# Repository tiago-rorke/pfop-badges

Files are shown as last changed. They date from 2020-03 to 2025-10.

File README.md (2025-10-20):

# Badges from Other Planets

I made these supercapacitor powered badges for [Nowhere 2019](https://www.goingnowhere.org/), a regional burn near Zaragoza, Spain, for our fledgling barrio "People from Other Planets".

I wanted to try to use supercapacitors to avoid consuming hundreds of non-rechargeable coin cell batteries whilst keeping the design as simple as possible. Because 5V supercaps are considerably more expensive, I've used a pair of 2.5V caps in series, with a 2.5V zener across each cap to prevent overcharging.  Not sure of the safety of this, the small amount of the use these boards have seen so far haven't yet led to any explosions, but none-the-less **use these at your own risk!**

I settled on a pair of 4.7F caps in series as a balance between cost/size/capacity, which for these two example sketches seem to provide around an hour of interaction and blinking lights after about 1 min of charging.  Without PWM the LEDs I chose are blindingly bright, I would suggest using larger resistors or different LEDs.

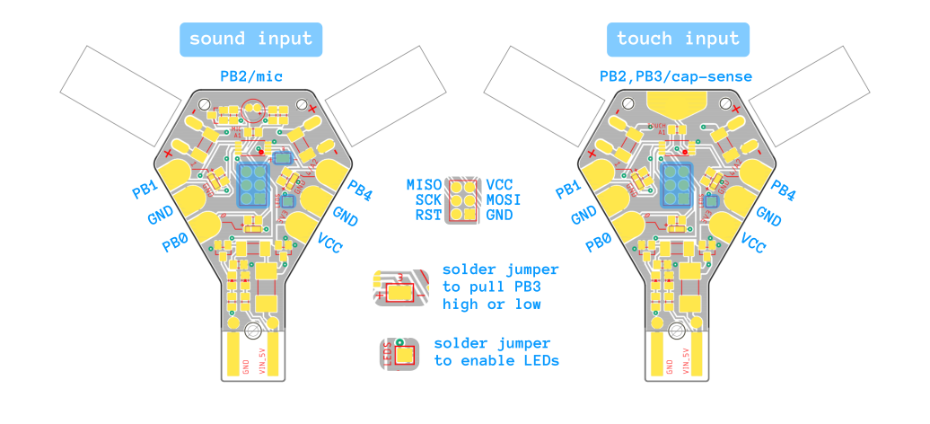
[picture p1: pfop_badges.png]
PFOP badges pinouts


There are two versions of the board, one with an eletret microphone and amplifier for reacting to sound, the other with a 2.2M resistor for doing capacitive touch sensing.

The charging circuit uses a mosfet and zener to switch on a green LED once the capacitors are fully charged.  I originally used a 5.1V zener which worked in the prototype circuit, but this didn't work with the zeners I put on the finished boards, maybe the 5.1V is a bit too high for usb voltages. I later experimented with some different values and eventually settled on a 3.9V zener that seemed to work well. Not sure why the zener voltage had to be so low, but the green LED would only start to turn on as the circuit approached the USB voltage.  The usb VBUS contact is split in two, to simultaneously connect a red led when the board is plugged in to charge, a hack which seems to work most of the time.  The capacitor inrush current is limited by a 1W resistor, which can get a bit toasty and should probably be bigger.

I made some adafruit inspired led-sequins, along with some sewable transistor break-outs, which are included in the board layouts.

The silkscreen designs on the back of the boards are by fellow bairro member [Luke Andrews](http://lukeandrewsdesign.com/), and the PFOP logo is by the barrio lead [Rob Allison](http://www.robertallison.co.uk/).

We also disassembled a bunch of old laptop batteries, removed any good cells and put them into [empty powerbanks](https://www.aliexpress.com/item/32966395604.html) to provide charging units for the badges, and to use as power sources for other activities we did at the burn in our desert makerspace :).

## BOM

| | | qty |
|---|---|---|
| capacitors 4.7F | [farnell](https://pt.farnell.com/samxon/dre475s0eg20rrdap/cap-4-7f-2-5v-double-layer-radial/dp/2800103) | 2 |
| attiny45 | [mouser](https://pt.mouser.com/ProductDetail/Microchip-Technology-Atmel/ATTINY45-20XU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) | 1 |
| white leds | [TME](https://www.tme.eu/pt/en/details/ll-r3014w-w5m-q10/smd-white-leds/lucky-light/) | 3 |
| red led | [TME](https://www.tme.eu/pt/en/details/ll-s172sc-2s/smd-colour-leds/lucky-light/) | 1 |
| green led | [TME](https://www.tme.eu/pt/en/details/el17-215sygc_53/smd-colour-leds/everlight/) | 1 |
| 3.3v regulator | [TME](https://www.tme.eu/pt/en/details/ap7313-33srg-7/ldo-unregulated-voltage-regulators/diodes-incorporated/) | 1 |
| 2.7v zener | [TME](https://www.tme.eu/pt/en/details/tzmb2v7-gs08/smd-zener-diodes/vishay/) | 2 |
| 3.9v zener | [TME](https://www.tme.eu/pt/en/details/bzv55c3v9-lge/smd-zener-diodes/luguang-electronic/bzv55c3v9/) | 1 |
| 2n7000 mosfet | [TME](https://www.tme.eu/pt/en/details/2n7002lt1g/smd-n-channel-transistors/on-semiconductor/) | 1 |
| resistor power 5.6R 1W | [TME](https://www.tme.eu/pt/en/details/smd2512-5r6/2512-smd-resistors/royal-ohm/25121wj056jt4e/) | 1 |
| resistor led 100R | [TME](https://www.tme.eu/pt/en/details/rc0805fr-07100r/0805-smd-resistors/yageo/rc0805fr-07100rl/) | 5 |
| resistor 10k | [TME](https://www.tme.eu/pt/en/details/smd0805-10k-1%25/0805-smd-resistors/royal-ohm/0805s8f1002t5e/) | 1 |
| *touch version* | | |
| resistor 2.2M | [TME](https://www.tme.eu/pt/en/details/smd0805-2m2/0805-smd-resistors/royal-ohm/0805s8j0225t5e/) | 1 |
| *sound version* | | |
| electret microphone | [aliexpress](https://www.aliexpress.com/item/10pcs-bag-4-5-2-2mm-condenser-electret-microphone-pickup-52DB/32262612470.html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,searchweb201602_7_10065_10068_319_10059_10884_317_10887_10696_321_322_10084_453_10083_454_10103_10618_10304_10307_10820_10301_10821_537_536,searchweb201603_52,ppcSwitch_0&algo_expid=e5ac956f-4788-4c7e-8c49-3e065ae08252-0&algo_pvid=e5ac956f-4788-4c7e-8c49-3e065ae08252) | 1 |
| bc847 transistor | [TME](https://www.tme.eu/pt/en/details/bc847be6327/npn-smd-transistors/infineon-technologies/) | 1 |
| resistor 10k | [TME](https://www.tme.eu/pt/en/details/smd0805-10k-1%25/0805-smd-resistors/royal-ohm/0805s8f1002t5e/) | 1 |
| resistor 100k | [TME](https://www.tme.eu/pt/en/details/crcw0805100kfktabc/0805-smd-resistors/vishay/) | 1 |
| cap 0.1uF | [TME](https://www.tme.eu/pt/en/details/cc0805krx7r9104/0805-mlcc-smd-capacitors/yageo/cc0805krx7r9bb104/) | 1 |

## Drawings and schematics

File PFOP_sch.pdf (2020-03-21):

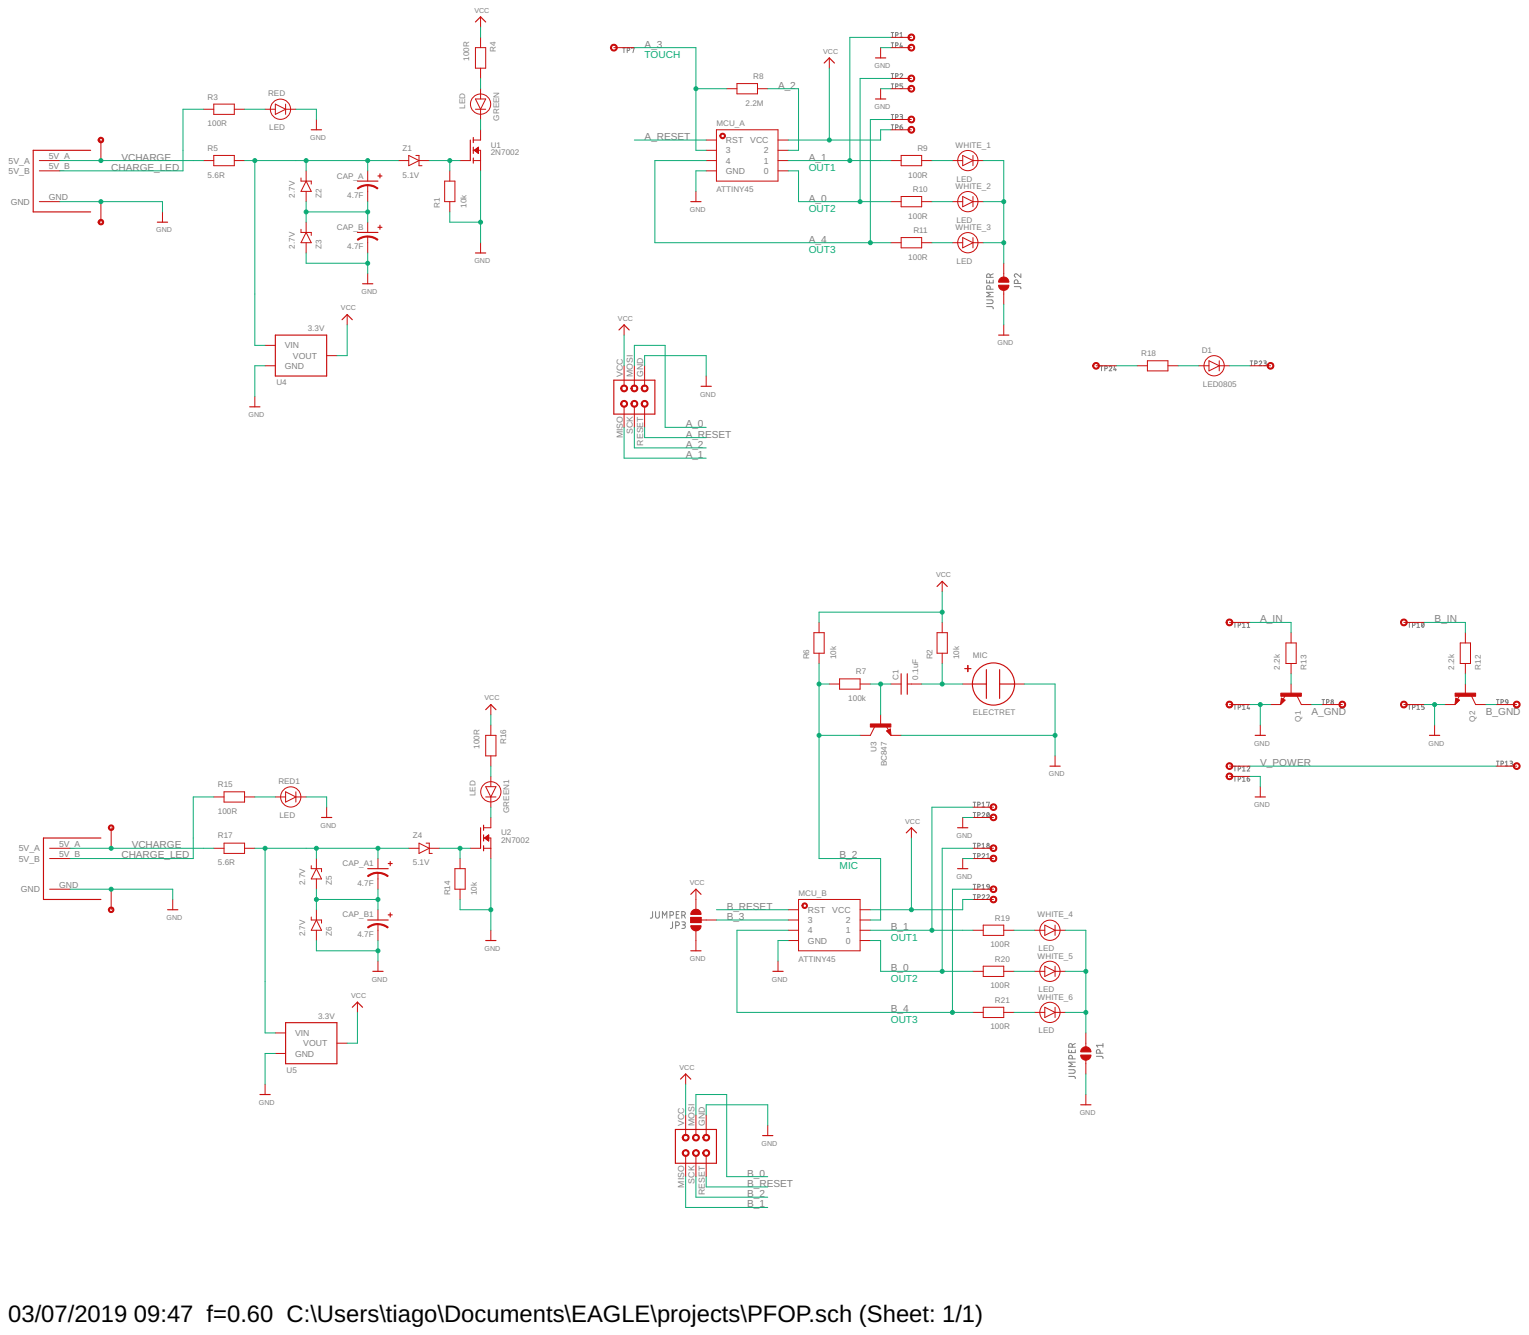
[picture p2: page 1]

SCK RESET GND MOSI VCC

03/07/2019 09:47 f=0.60 C:\Users\tiago\Documents\EAGLE\projects\PFOP.sch (Sheet: 1/1)

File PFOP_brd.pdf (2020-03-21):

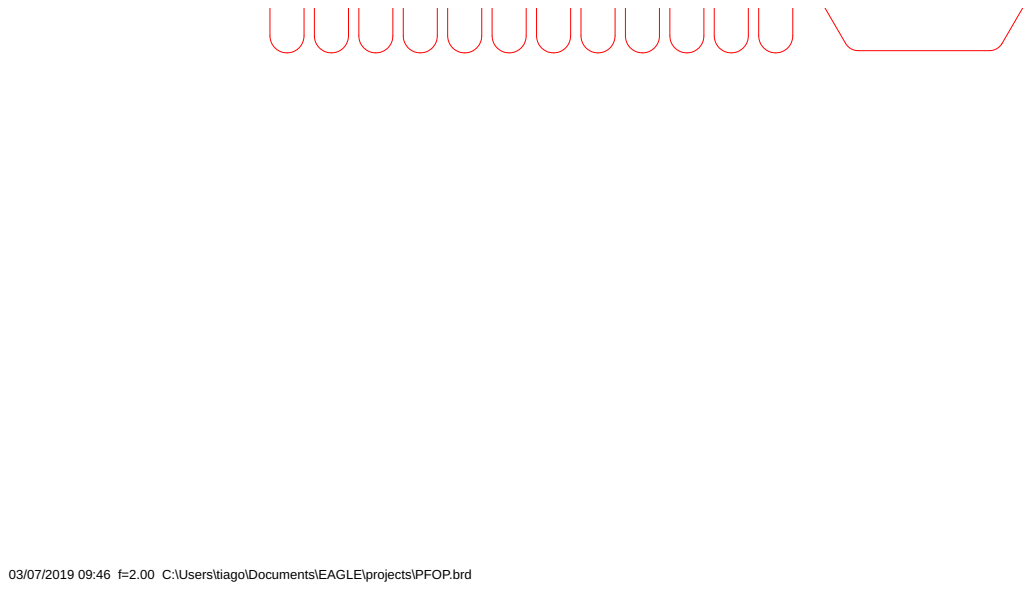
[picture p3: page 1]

03/07/2019 09:46 f=2.00 C:\Users\tiago\Documents\EAGLE\projects\PFOP.brd

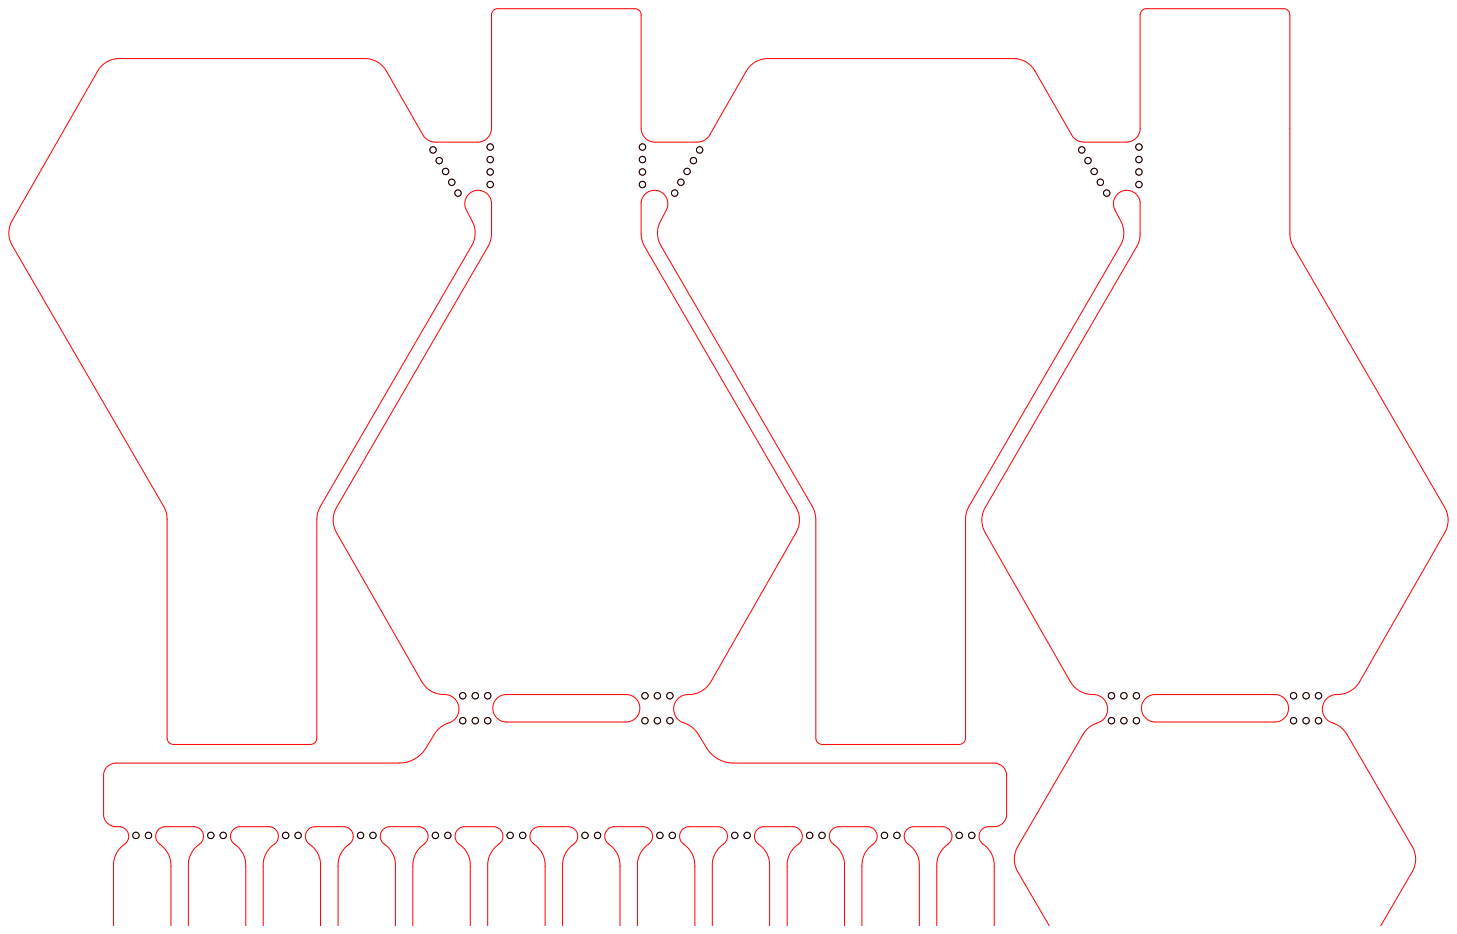
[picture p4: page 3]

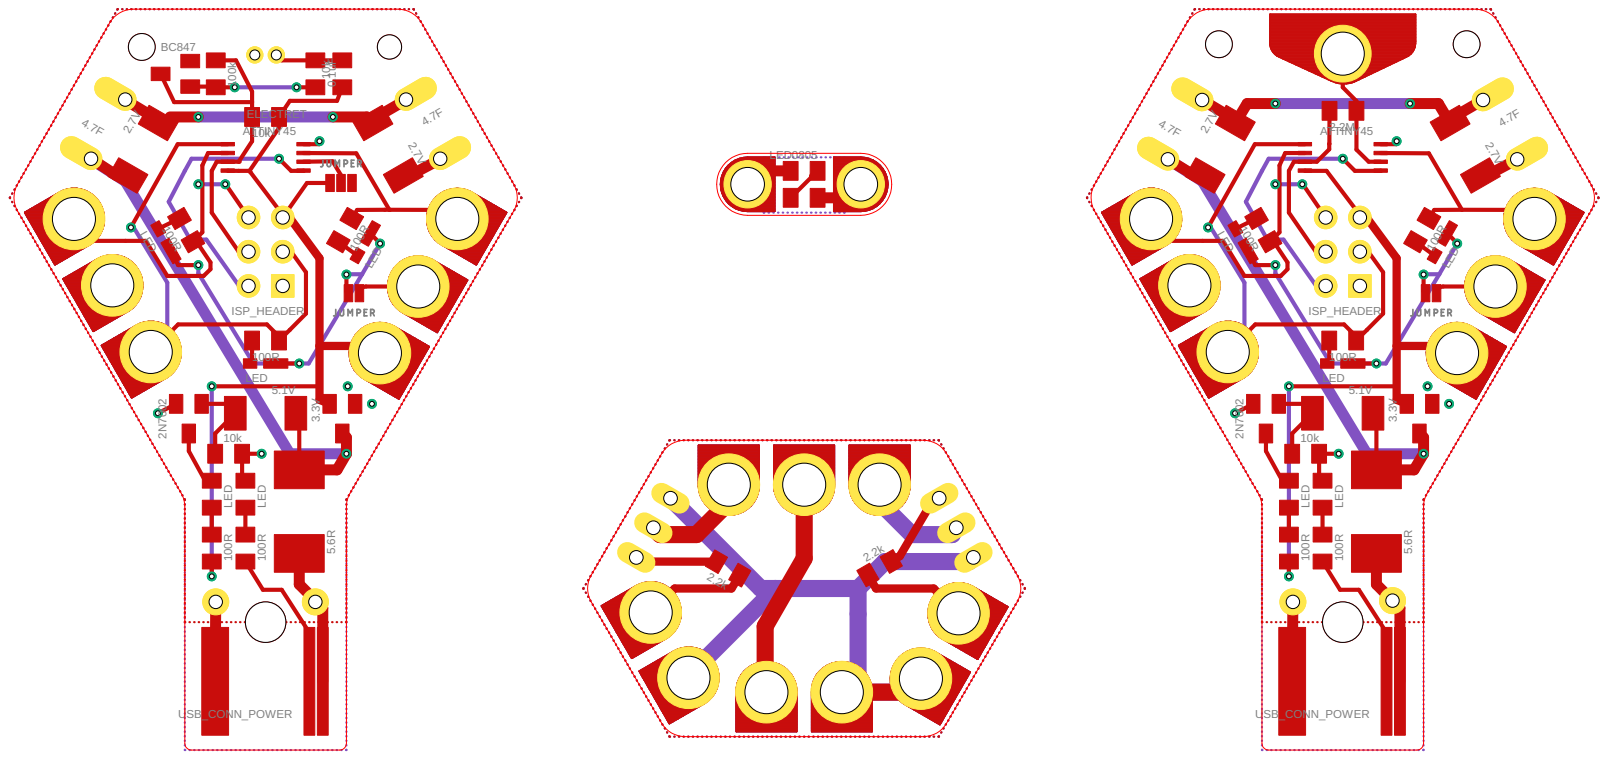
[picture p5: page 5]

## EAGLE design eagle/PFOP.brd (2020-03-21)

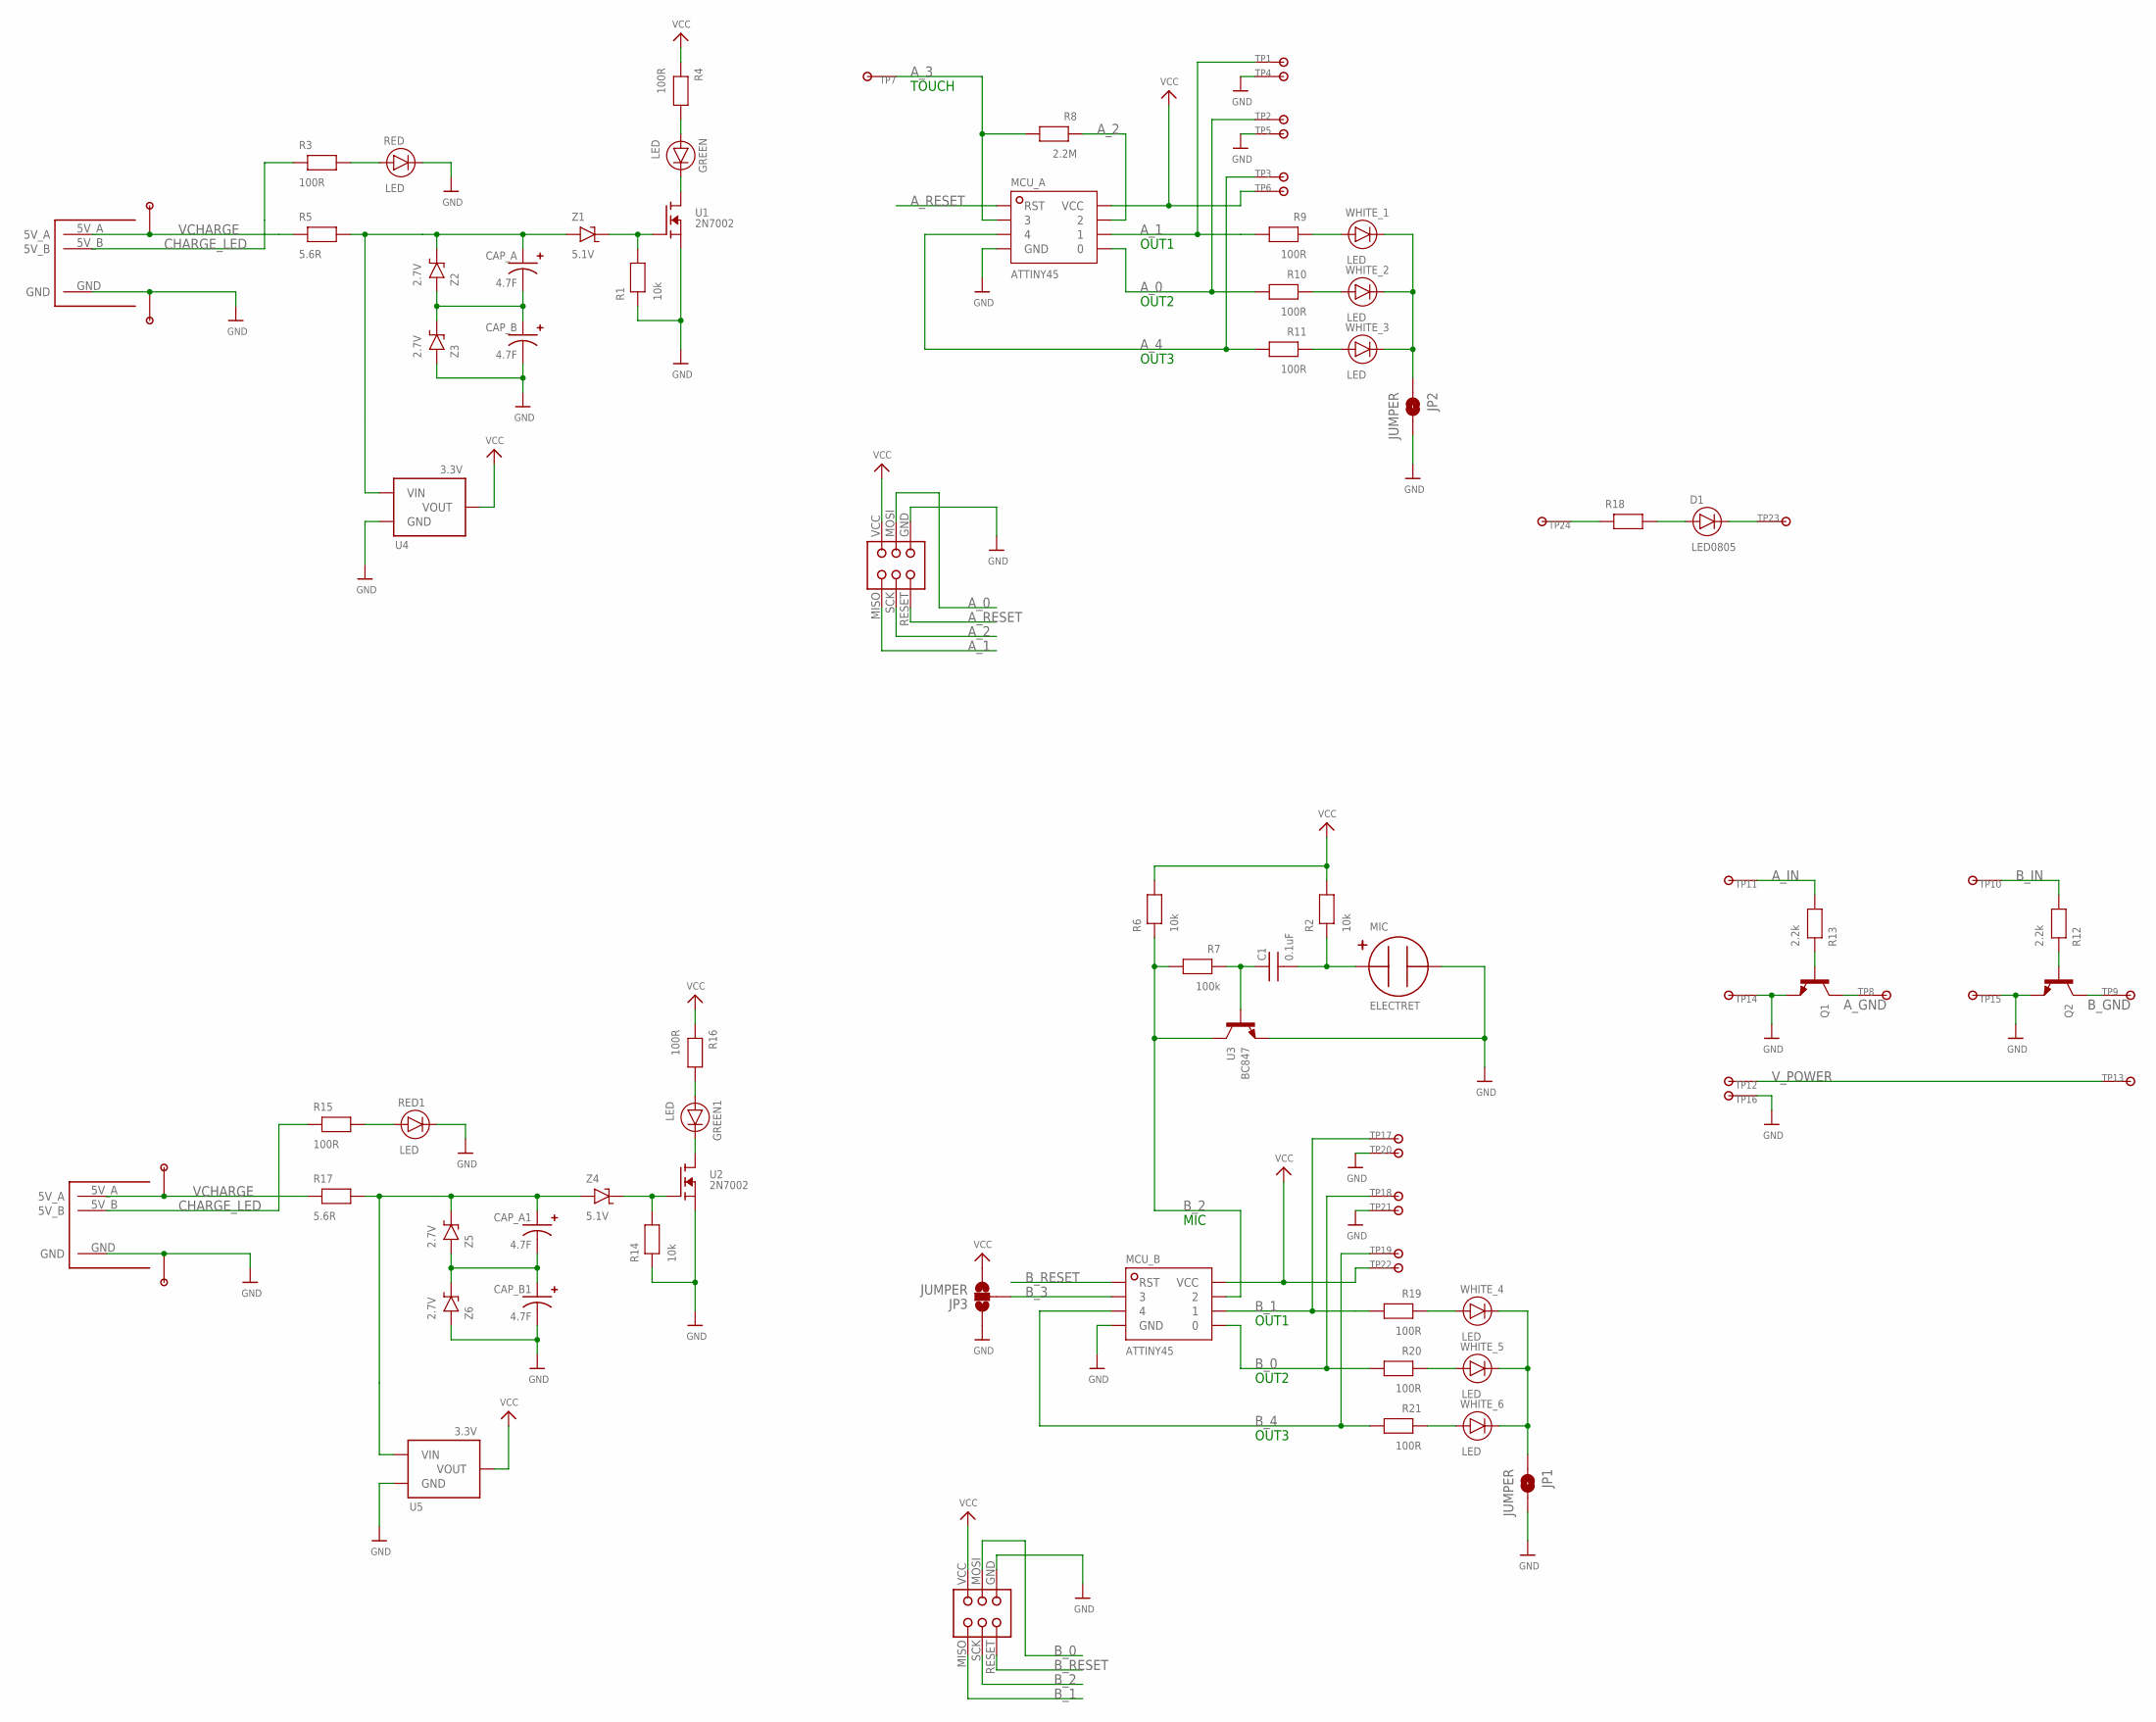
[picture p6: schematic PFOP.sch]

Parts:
C1: 0.1uF; 0805
CAP_A, CAP_A1: 4.7F; SUPERCAP_2.7V-4.7F
CAP_B, CAP_B1: 4.7F; SUPERCAP_2.7V-4.7F
D1: LED0805; 0805_LED
GREEN, GREEN1: LED; 0805_LED
J1, J2: ISP_HEADER
JP1, JP2: JUMPER; SMT-JUMPER_2_NO_NO-SILK
JP3: JUMPER; SMT-JUMPER_3_NO_NO-SILK
MCU_A: ATTINY45; TSSOP-8
MCU_B: ATTINY45; TSSOP-8
MIC: ELECTRET; ELECTRET_4.5MM
Q1, Q2: POWER_TRANSISTOR
R1, R2, R6, R14: 10k; 0805
R3, R4, R9, R10, R11, R15, R16, R19, R20, R21: 100R; 0805
R5, R17: 5.6R; 2512
R7: 100k; 0805
R8: 2.2M; 0805
R12, R13: 2.2k; 0805
R18: RESISTOR; 0805
RED, RED1: LED; 0805_LED
TP1, TP2, TP3, TP4, TP5, TP6, TP8, TP9, TP10, TP11, TP12, TP13, TP14, TP15, TP16, TP17, TP18, TP19, TP20, TP21, TP22: SEWTAPBIG; BIGTAP
TP7: SEWTAP; BIGTAP_TOUCH
TP23, TP24: SEWTAPSEQUIN; SEQUIN_TERMINAL
U1, U2: 2N7002; SOT23
U3: BC847; SOT23
U4, U5: 3.3V; SOT23
U$1, U$4: USB_CONN_POWER
U$2, U$3, U$5, U$6: 1PIN
WHITE_1, WHITE_2, WHITE_3, WHITE_4, WHITE_5, WHITE_6: LED; PLCC-2_LED
Z1, Z4: 5.1V; MINIMELF
Z2, Z3, Z5, Z6: 2.7V; MINIMELF

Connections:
A_0: J1.MOSI, MCU_A.5 (0), R10.2, TP2.P$1
A_1: J1.MISO, MCU_A.6 (1), R9.2, TP1.P$1
A_2: J1.SCK, MCU_A.7 (2), R8.1
A_3: MCU_A.2 (3), R8.2, TP7.P$1
A_4: MCU_A.3 (4), R11.2, TP3.P$1
A_GND: Q1.C, TP8.P$1
A_IN: R13.2, TP11.P$1
A_RESET: J1.RESET, MCU_A.1 (RST)
B_0: J2.MOSI, MCU_B.5 (0), R20.2, TP18.P$1
B_1: J2.MISO, MCU_B.6 (1), R19.2, TP17.P$1
B_2: J2.SCK, MCU_B.7 (2), R6.1, R7.2, U3.3 (C)
B_3: JP3.2, MCU_B.2 (3)
B_4: MCU_B.3 (4), R21.2, TP19.P$1
B_GND: Q2.C, TP9.P$1
B_IN: R12.2, TP10.P$1
B_RESET: J2.RESET, MCU_B.1 (RST)
CHARGE_LED: R3.1, R15.1, U$1.5V_B, U$4.5V_B
GND: CAP_B.-, CAP_B1.-, J1.GND, J2.GND, JP1.2, JP2.2, JP3.1, MCU_A.4 (GND), MCU_B.4 (GND), MIC.- (V-), Q1.E, Q2.E, R1.1, R14.1, RED.-, RED1.-, TP4.P$1, TP5.P$1, TP14.P$1, TP15.P$1, TP16.P$1, TP20.P$1, TP21.P$1, U1.2 (S), U2.2 (S), U3.2 (E), U4.1 (GND), U5.1 (GND), U$1.GND, U$3.P$1, U$4.GND, U$6.P$1, Z3.1, Z6.1
unnamed: R3.2, RED.+
unnamed: R15.2, RED1.+
unnamed: R1.2, U1.1 (G), Z1.2
unnamed: GREEN.-, U1.3 (D)
unnamed: CAP_A.-, CAP_B.+, Z2.1, Z3.2
unnamed: R14.2, U2.1 (G), Z4.2
unnamed: GREEN.+, R4.2
unnamed: C1.2, MIC.+ (V+), R2.1
unnamed: GREEN1.-, U2.3 (D)
unnamed: C1.1, R7.1, U3.1 (B)
unnamed: Q2.B, R12.1
unnamed: CAP_A1.-, CAP_B1.+, Z5.1, Z6.2
unnamed: GREEN1.+, R16.2
unnamed: R9.1, WHITE_1.+
unnamed: R10.1, WHITE_2.+
unnamed: R11.1, WHITE_3.+
unnamed: JP2.1, WHITE_1.-, WHITE_2.-, WHITE_3.-
unnamed: R19.1, WHITE_4.+
unnamed: R20.1, WHITE_5.+
unnamed: Q1.B, R13.1
unnamed: R21.1, WHITE_6.+
unnamed: JP1.1, WHITE_4.-, WHITE_5.-, WHITE_6.-
unnamed: R18.1, TP24.P$1
unnamed: D1.+, R18.2
unnamed: D1.-, TP23.P$1
VCAP: CAP_A.+, R5.2, U4.3 (VIN), Z1.1, Z2.2
VCAP1: CAP_A1.+, R17.2, U5.3 (VIN), Z4.1, Z5.2
VCC: J1.VCC, J2.VCC, JP3.3, MCU_A.8 (VCC), MCU_B.8 (VCC), R2.2, R4.1, R6.2, R16.1, TP6.P$1, TP22.P$1, U4.2 (VOUT), U5.2 (VOUT)
VCHARGE: R5.1, R17.1, U$1.5V_A, U$2.P$1, U$4.5V_A, U$5.P$1
V_POWER: TP12.P$1, TP13.P$1

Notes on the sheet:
TOUCH
OUT1
OUT2
OUT3
MIC

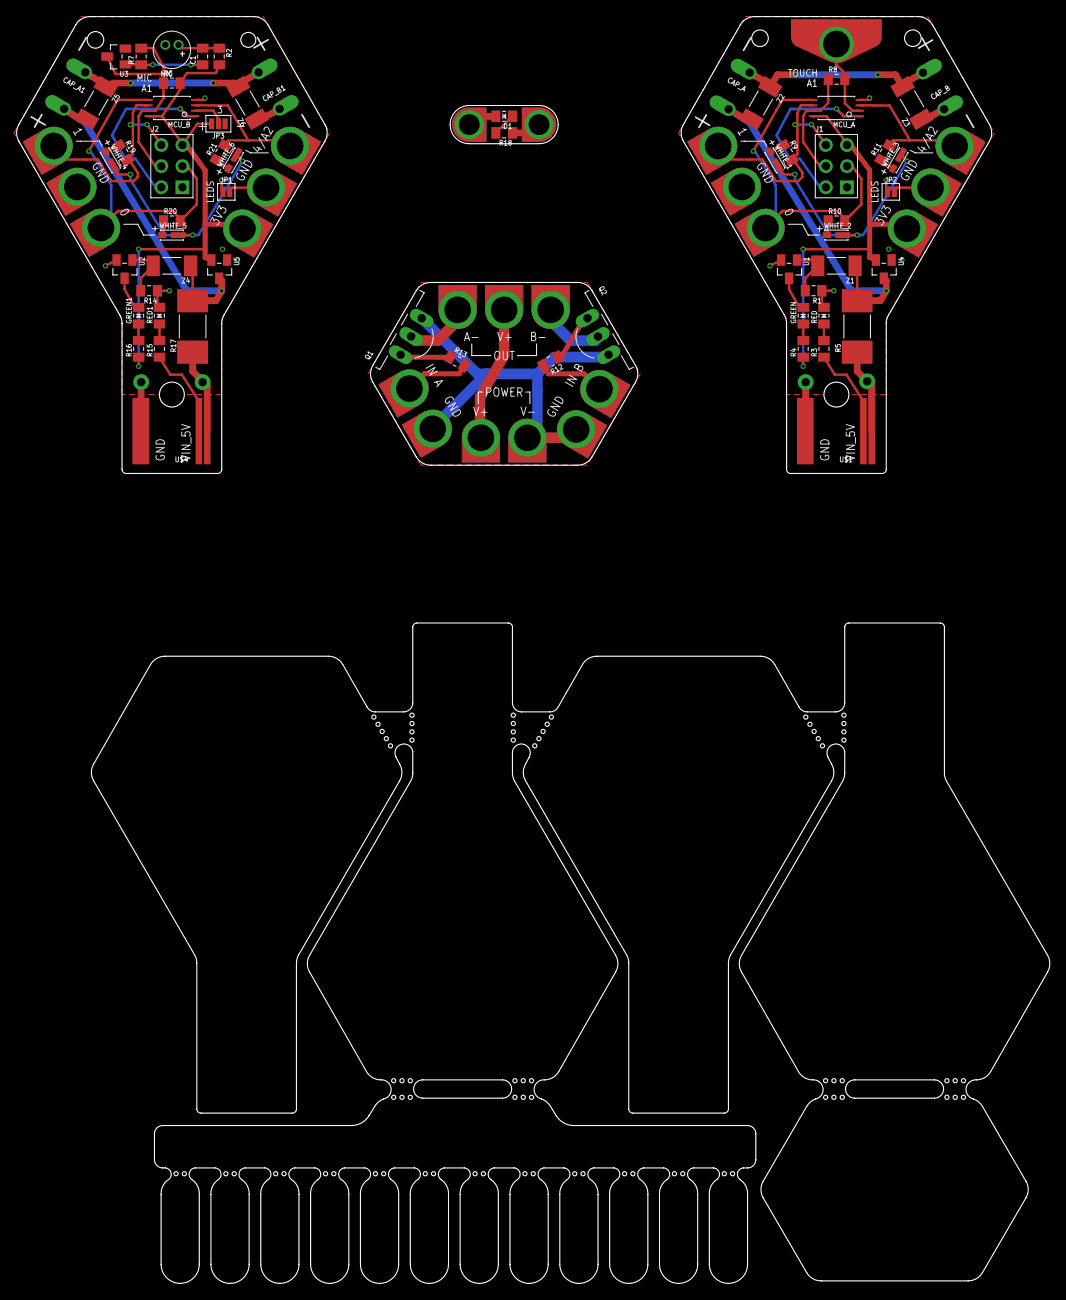
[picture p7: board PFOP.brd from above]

Board: 2 copper layers, 124.4 x 152.5 mm, 88 parts (0 on the bottom side), 48 nets.

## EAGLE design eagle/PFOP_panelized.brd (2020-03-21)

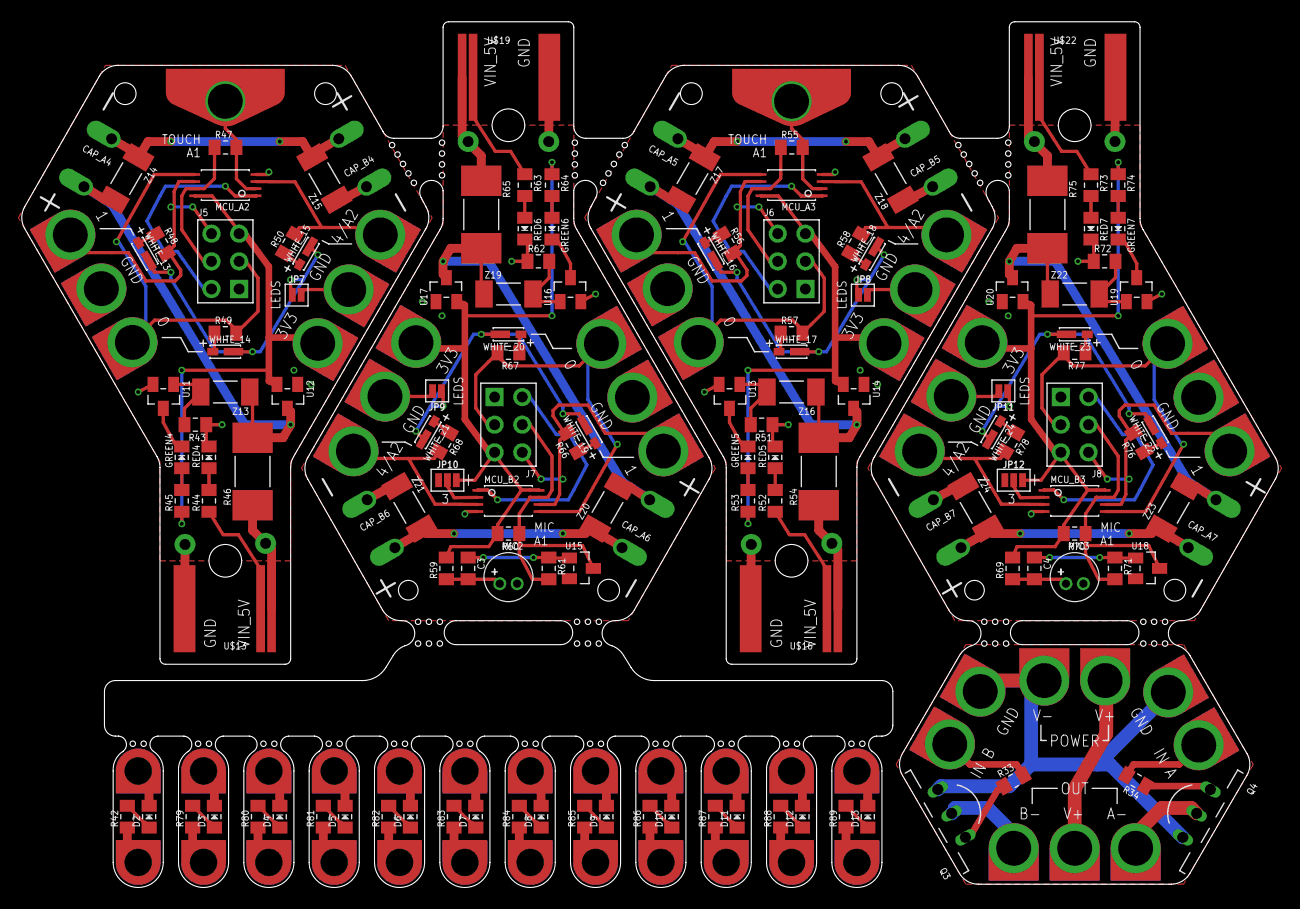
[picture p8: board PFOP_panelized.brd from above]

Board: 2 copper layers, 115.4 x 79.5 mm, 203 parts (0 on the bottom side), 128 nets.

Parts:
C3, C4: 0.1uF; 0805
CAP_A4, CAP_A5, CAP_A6, CAP_A7: 4.7F; SUPERCAP_2.7V-4.7F
CAP_B4, CAP_B5, CAP_B6, CAP_B7: 4.7F; SUPERCAP_2.7V-4.7F
D2, D3, D4, D5, D6, D7, D8, D9, D10, D11, D12, D13: LED0805; 0805_LED
GREEN4, GREEN5, GREEN6, GREEN7: LED; 0805_LED
J5, J6, J7, J8: ISP_HEADER
JP7, JP8, JP9, JP11: JUMPER; SMT-JUMPER_2_NO_NO-SILK
JP10, JP12: JUMPER; SMT-JUMPER_3_NO_NO-SILK
MCU_A2, MCU_A3: ATTINY45; TSSOP-8
MCU_B2, MCU_B3: ATTINY45; TSSOP-8
MIC2, MIC3: ELECTRET; ELECTRET_4.5MM
Q3, Q4: POWER_TRANSISTOR
R33, R34: 2.2k; 0805
R42, R79, R80, R81, R82, R83, R84, R85, R86, R87, R88, R89: 0805
R43, R51, R59, R60, R62, R69, R70, R72: 10k; 0805
R44, R45, R48, R49, R50, R52, R53, R56, R57, R58, R63, R64, R66, R67, R68, R73, R74, R76, R77, R78: 100R; 0805
R46, R54, R65, R75: 5.6R; 2512
R47, R55: 2.2M; 0805
R61, R71: 100k; 0805
RED4, RED5, RED6, RED7: LED; 0805_LED
TP32, TP33, TP34, TP35, TP36, TP37, TP38, TP39, TP40, TP49, TP50, TP51, TP52, TP53, TP54, TP56, TP57, TP58, TP59, TP60, TP61, TP63, TP64, TP65, TP66, TP67, TP68, TP69, TP70, TP71, TP72, TP73, TP74: SEWTAPBIG; BIGTAP
TP47, TP48, TP75, TP76, TP77, TP78, TP79, TP80, TP81, TP82, TP83, TP84, TP85, TP86, TP87, TP88, TP89, TP90, TP91, TP92, TP93, TP94, TP95, TP96: SEWTAPSEQUIN; SEQUIN_TERMINAL
TP55, TP62: SEWTAP; BIGTAP_TOUCH
U11, U13, U16, U19: 2N7002; SOT23
U12, U14, U17, U20: 3.3V; SOT23
U15, U18: BC847; SOT23
U$13, U$16, U$19, U$22: USB_CONN_POWER
U$14, U$15, U$17, U$18, U$20, U$21, U$23, U$24: 1PIN
WHITE_13, WHITE_14, WHITE_15, WHITE_16, WHITE_17, WHITE_18, WHITE_19, WHITE_20, WHITE_21, WHITE_22, WHITE_23, WHITE_24: LED; PLCC-2_LED
Z13, Z16, Z19, Z22: 5.1V; MINIMELF
Z14, Z15, Z17, Z18, Z20, Z21, Z23, Z24: 2.7V; MINIMELF

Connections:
A_10: J5.SCK, MCU_A2.7, R47.1
A_11: MCU_A2.2, R47.2, TP55.P$1
A_12: MCU_A2.3, R50.2, TP51.P$1
A_13: J5.MOSI, MCU_A2.5, R49.2, TP50.P$1
A_14: J5.MISO, MCU_A2.6, R48.2, TP49.P$1
A_15: J6.SCK, MCU_A3.7, R55.1
A_16: MCU_A3.2, R55.2, TP62.P$1
A_17: MCU_A3.3, R58.2, TP58.P$1
A_18: J6.MOSI, MCU_A3.5, R57.2, TP57.P$1
A_19: J6.MISO, MCU_A3.6, R56.2, TP56.P$1
A_GND1: Q4.C, TP32.P$1
A_IN1: R34.2, TP35.P$1
A_RESET2: J5.RESET, MCU_A2.1
A_RESET3: J6.RESET, MCU_A3.1
B_10: J7.SCK, MCU_B2.7, R60.1, R61.2, U15.3
B_11: J7.MOSI, MCU_B2.5, R67.2, TP64.P$1
B_12: J7.MISO, MCU_B2.6, R66.2, TP63.P$1
B_13: MCU_B2.3, R68.2, TP65.P$1
B_14: JP10.2, MCU_B2.2
B_15: J8.SCK, MCU_B3.7, R70.1, R71.2, U18.3
B_16: J8.MOSI, MCU_B3.5, R77.2, TP70.P$1
B_17: J8.MISO, MCU_B3.6, R76.2, TP69.P$1
B_18: MCU_B3.3, R78.2, TP71.P$1
B_19: JP12.2, MCU_B3.2
B_GND1: Q3.C, TP33.P$1
B_IN1: R33.2, TP34.P$1
B_RESET2: J7.RESET, MCU_B2.1
B_RESET3: J8.RESET, MCU_B3.1
CHARGE_LED2: R44.1, U$13.5V_B
CHARGE_LED3: R52.1, U$16.5V_B
CHARGE_LED4: R63.1, U$19.5V_B
CHARGE_LED5: R73.1, U$22.5V_B
GND2: CAP_B4.-, J5.GND, JP7.2, MCU_A2.4, R43.1, RED4.-, TP52.P$1, TP53.P$1, U11.2, U12.1, U$13.GND, U$15.P$1, Z15.1
GND3: CAP_B5.-, J6.GND, JP8.2, MCU_A3.4, R51.1, RED5.-, TP59.P$1, TP60.P$1, U13.2, U14.1, U$16.GND, U$18.P$1, Z18.1
GND4: CAP_B6.-, J7.GND, JP9.2, JP10.1, MCU_B2.4, MIC2.-, R62.1, RED6.-, TP66.P$1, TP67.P$1, U15.2, U16.2, U17.1, U$19.GND, U$21.P$1, Z21.1
GND5: CAP_B7.-, J8.GND, JP11.2, JP12.1, MCU_B3.4, MIC3.-, R72.1, RED7.-, TP72.P$1, TP73.P$1, U18.2, U19.2, U20.1, U$22.GND, U$24.P$1, Z24.1
unnamed: Q3.B, R33.1
unnamed: Q4.B, R34.1
unnamed: R42.1, TP48.P$1
unnamed: D2.+, R42.2
unnamed: D2.-, TP47.P$1
unnamed: R44.2, RED4.+
unnamed: R43.2, U11.1, Z13.2
unnamed: GREEN4.-, U11.3
unnamed: CAP_A4.-, CAP_B4.+, Z14.1, Z15.2
unnamed: GREEN4.+, R45.2
unnamed: R48.1, WHITE_13.+
unnamed: R49.1, WHITE_14.+
unnamed: R50.1, WHITE_15.+
unnamed: JP7.1, WHITE_13.-, WHITE_14.-, WHITE_15.-
unnamed: R52.2, RED5.+
unnamed: R51.2, U13.1, Z16.2
unnamed: GREEN5.-, U13.3
unnamed: CAP_A5.-, CAP_B5.+, Z17.1, Z18.2
unnamed: GREEN5.+, R53.2
unnamed: R56.1, WHITE_16.+
unnamed: R57.1, WHITE_17.+
unnamed: R58.1, WHITE_18.+
unnamed: JP8.1, WHITE_16.-, WHITE_17.-, WHITE_18.-
unnamed: C3.2, MIC2.+, R59.1
unnamed: C3.1, R61.1, U15.1
unnamed: R63.2, RED6.+
unnamed: R62.2, U16.1, Z19.2
unnamed: GREEN6.-, U16.3
unnamed: CAP_A6.-, CAP_B6.+, Z20.1, Z21.2
unnamed: GREEN6.+, R64.2
unnamed: R66.1, WHITE_19.+
unnamed: R67.1, WHITE_20.+
unnamed: R68.1, WHITE_21.+
unnamed: JP9.1, WHITE_19.-, WHITE_20.-, WHITE_21.-
unnamed: C4.2, MIC3.+, R69.1
unnamed: C4.1, R71.1, U18.1
unnamed: R73.2, RED7.+
unnamed: R72.2, U19.1, Z22.2
unnamed: GREEN7.-, U19.3
unnamed: CAP_A7.-, CAP_B7.+, Z23.1, Z24.2
unnamed: GREEN7.+, R74.2
unnamed: R76.1, WHITE_22.+
unnamed: R77.1, WHITE_23.+
unnamed: R78.1, WHITE_24.+
unnamed: JP11.1, WHITE_22.-, WHITE_23.-, WHITE_24.-
unnamed: R79.1, TP76.P$1
unnamed: D3.+, R79.2
unnamed: D3.-, TP75.P$1
unnamed: R80.1, TP78.P$1
unnamed: D4.+, R80.2
unnamed: D4.-, TP77.P$1
unnamed: R81.1, TP80.P$1
unnamed: D5.+, R81.2
unnamed: D5.-, TP79.P$1
unnamed: R82.1, TP82.P$1
unnamed: D6.+, R82.2
unnamed: D6.-, TP81.P$1
unnamed: R83.1, TP84.P$1
unnamed: D7.+, R83.2
unnamed: D7.-, TP83.P$1
unnamed: R84.1, TP86.P$1
unnamed: D8.+, R84.2
unnamed: D8.-, TP85.P$1
unnamed: R85.1, TP88.P$1
unnamed: D9.+, R85.2
unnamed: D9.-, TP87.P$1
unnamed: R86.1, TP90.P$1
unnamed: D10.+, R86.2
unnamed: D10.-, TP89.P$1
unnamed: R87.1, TP92.P$1
unnamed: D11.+, R87.2
unnamed: D11.-, TP91.P$1
unnamed: R88.1, TP94.P$1
unnamed: D12.+, R88.2
unnamed: D12.-, TP93.P$1
unnamed: R89.1, TP96.P$1
unnamed: D13.+, R89.2
unnamed: D13.-, TP95.P$1
S$8: Q3.E, Q4.E, TP38.P$1, TP39.P$1, TP40.P$1
VCAP4: CAP_A4.+, R46.2, U12.3, Z13.1, Z14.2
VCAP5: CAP_A5.+, R54.2, U14.3, Z16.1, Z17.2
VCAP6: CAP_A6.+, R65.2, U17.3, Z19.1, Z20.2
VCAP7: CAP_A7.+, R75.2, U20.3, Z22.1, Z23.2
VCC2: J5.VCC, MCU_A2.8, R45.1, TP54.P$1, U12.2
VCC3: J6.VCC, MCU_A3.8, R53.1, TP61.P$1, U14.2
VCC4: J7.VCC, JP10.3, MCU_B2.8, R59.2, R60.2, R64.1, TP68.P$1, U17.2
VCC5: J8.VCC, JP12.3, MCU_B3.8, R69.2, R70.2, R74.1, TP74.P$1, U20.2
VCHARGE2: R46.1, U$13.5V_A, U$14.P$1
VCHARGE3: R54.1, U$16.5V_A, U$17.P$1
VCHARGE4: R65.1, U$19.5V_A, U$20.P$1
VCHARGE5: R75.1, U$22.5V_A, U$23.P$1
V_POWER1: TP36.P$1, TP37.P$1

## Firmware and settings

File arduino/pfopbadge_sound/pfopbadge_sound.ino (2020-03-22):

#define NUM_LEDS 3
const int LED_PIN[] = {0, 1, 4};


// ================== GENERAL VARS ================== //

// target led pwm level
#define BRIGHTNESS_MAX 30
#define BRIGHTNESS_MIN 5
// time spent at brightness
#define ON_DELAY_MAX 1000
#define ON_DELAY_MIN 100
// time before next led fade on
#define INTERVAL_MAX 3000
#define INTERVAL_MIN 1000
// fade speed
#define FADE_DELAY 20

// active == reacting to sound
boolean active = false;

long timer;

int pwm[NUM_LEDS];
int brightness[NUM_LEDS]; 

// random twinkling during passive state
long led_timer[NUM_LEDS];
int on_delay[NUM_LEDS]; 
int interval; 
int led_index; // "current" led in pattern
// individual led states
int led_state[NUM_LEDS];
  // -1 = led off, inactive
  // 0 = led off, waiting to fade on
  // 1 = fading led on
  // 2 = led at brightness, waiting to fade off
  // 3 = fading led off


// =================== SOUND VARS =================== //

#define SOUND_PIN A1

// to store adc microphone reading
int sound;

// set relative sound thresholds for each LED
int thres0 = 200;
int thres1 = 250;
int thres2 = 350;
int thres3 = 450;

// an offset for quickly tweaking the thresholds
int thres_mod = 80;

int sound_timeout = 1000;


void setup() {

  thres0 += thres_mod;
  thres1 += thres_mod;
  thres2 += thres_mod;

  for(int i=0; i<NUM_LEDS; i++) {
    pinMode(LED_PIN[i], OUTPUT);
  }
  init_leds();

  twinkling_init();
}


void loop() {

  update_leds();

  sound = analogRead(SOUND_PIN);

  if(!active && sound > thres0) {
    timer = millis();
    active = true;
    init_leds();
  } else if (active && millis()-timer > sound_timeout) {
    timer = millis();
    active = false;
    twinkling_init();
  }

  if(!active) { // leds are twinkling slowly
      
    long now = millis();

    for(int i=0; i<NUM_LEDS; i++) {   
      switch(led_state[i]) {

        case 0: // led off, waiting to fade on
          if(now - led_timer[i] > interval) {
            led_state[i] = 1;
            led_timer[i] = now;
            led_init(i);
            led_timer[i] = now;
          }
          break;

        case 1: // fading led on
          if(now - led_timer[i] > FADE_DELAY) {
            pwm[i]++;
            if(pwm[i] > brightness[i]) {
              pwm[i] = brightness[i];
              led_state[i] = 2;
            }
            led_timer[i] = now;
          }
          break;

        case 2: // led at brightness, waiting to fade off
          if(now - led_timer[i] > on_delay[i]) {
            led_state[i] = 3;
            led_timer[i] = now;
          }
          break;

        case 3: // fading led off
          if(now - led_timer[i] > FADE_DELAY) {
            pwm[i]--;
            if(pwm[i] < 0) {
              pwm[i] = 0;
              led_state[i] = -1;
              init_next_led();
            }
            led_timer[i] = now;
          }
          break;

      }
    }

  } else { // leds are reacting to sound    

    if (sound > thres0) {
      pwm[0] = map(sound, thres0, thres1, 0, BRIGHTNESS_MAX);
    } else {
      pwm[0] = 0;
    }
    if (sound > thres1) {
      pwm[1] = map(sound, thres1, thres2, 0, BRIGHTNESS_MAX);
    } else {
      pwm[1] = 0;
    }
    if (sound > thres2) {
      pwm[2] = map(sound, thres2, thres3, 0, BRIGHTNESS_MAX);
    } else {
      pwm[2] = 0;
    }

  }
}


void init_leds() {
  for(int i=0; i<NUM_LEDS; i++) {
    pwm[i] = 0;
    digitalWrite(LED_PIN[i], LOW);
  }

}

void update_leds() {
  for(int i=0; i<NUM_LEDS; i++) { 
    if(pwm[i] > 0) {
      analogWrite(LED_PIN[i], pwm[i]);
    } else {
      digitalWrite(LED_PIN[i], LOW);
    }    
  }  
}

void twinkling_init() {
  interval = random(INTERVAL_MIN, INTERVAL_MAX);
  for(int i=0; i<NUM_LEDS; i++) {
    led_state[i] = -1;
  }
  led_index = floor(random(0,3));
  led_init(led_index);
  init_next_led();
  timer = millis();
  init_leds();
}

void led_init(int led) {
  led_state[led] = 1;
  brightness[led] = random(BRIGHTNESS_MIN, BRIGHTNESS_MAX);
  on_delay[led] = random(ON_DELAY_MIN, ON_DELAY_MAX);
}

void init_next_led() {
  if(random(0,2) > 0) {
    led_index++;
  } else {
    led_index--;
  }
  if(led_index<0) {
    led_index = NUM_LEDS -1;
  } else {
    led_index %= NUM_LEDS;
  }
  if(led_state[led_index] == -1) {
    led_state[led_index] = 0;
    interval = random(INTERVAL_MIN, INTERVAL_MAX);
  } else {
    init_next_led();
  }
}

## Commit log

2020-03-21 readme edits
    [PFOP.brd, PFOP.sch, PFOP_panelized.brd]
2020-03-22 add arduino sketches
    [PFOP.brd, PFOP.sch, PFOP_panelized.brd]
